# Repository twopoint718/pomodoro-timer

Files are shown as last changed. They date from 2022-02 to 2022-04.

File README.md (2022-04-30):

Pomodoro Timer
==============

A desktop pomodoro timer.

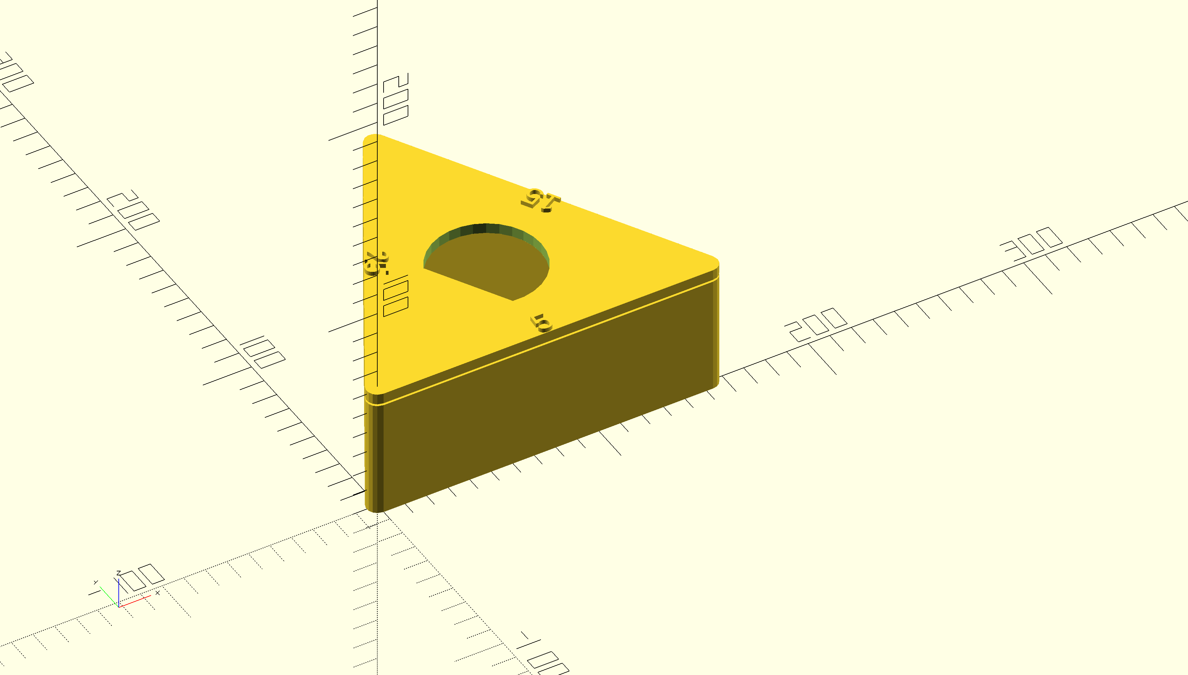
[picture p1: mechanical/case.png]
A rendered view of the case


Peripherals
-----------

- [PCD8544](https://learn.adafruit.com/nokia-5110-3310-monochrome-lcd) 84x48 pixel LCD screen (SPI-based)
- [LSM6DSL](https://www.st.com/resource/en/datasheet/lsm6dsl.pdf) (PDF) iNEMO inertial module always-on 3D accelerometer and 3D gyroscope (I2C)
- TIM (General-purpose timer, onboard)
- GPIO reset button
- UART (onboard)

Code
----

I've either referenced, ported, or otherwise used these open source projects in my own:

- [Adafruit GFX Library](https://github.com/Adafruit/Adafruit-GFX-Library), [BSD License](https://github.com/adafruit/Adafruit-GFX-Library/blob/master/license.txt)
- [STMicroelectronics LSM6DSL accelerometer/gyro driver](https://github.com/STMicroelectronics/stm32-lsm6dsl), [BSD License](https://opensource.org/licenses/BSD-3-Clause)
- [STMicroelectronics HAL code](https://www.st.com/resource/en/user_manual/um1884-description-of-stm32l4l4-hal-and-lowlayer-drivers-stmicroelectronics.pdf) (PDF)
- [8x8 VGA Font](https://github.com/dhepper/font8x8), Public Domain License

Building
--------

Be sure to have already installed the [Arm GNU Toolchain](https://developer.arm.com/tools-and-software/open-source-software/developer-tools/gnu-toolchain).
Then this project can be built by the Makefile in the root directory.

```
make -j
```

Building under Windows
----------------------

TODO

Presentations
-------------

- 8LU Keynote by Chris Wilson: Embedded–From the point of view of a web developer
  [YouTube Link](https://youtu.be/wSTIfWqJzPw)

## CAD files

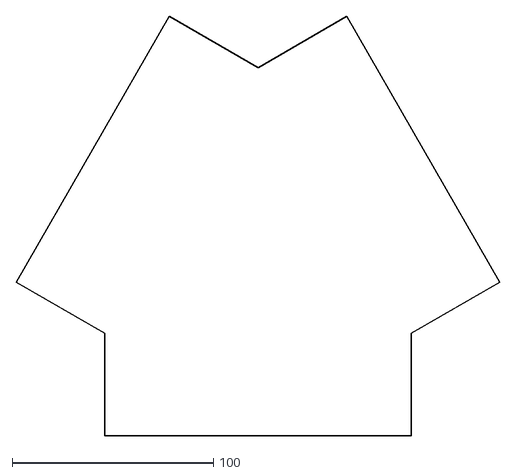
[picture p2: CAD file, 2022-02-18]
mechanical/pom_drawing.dxf
240.4 x 208.2

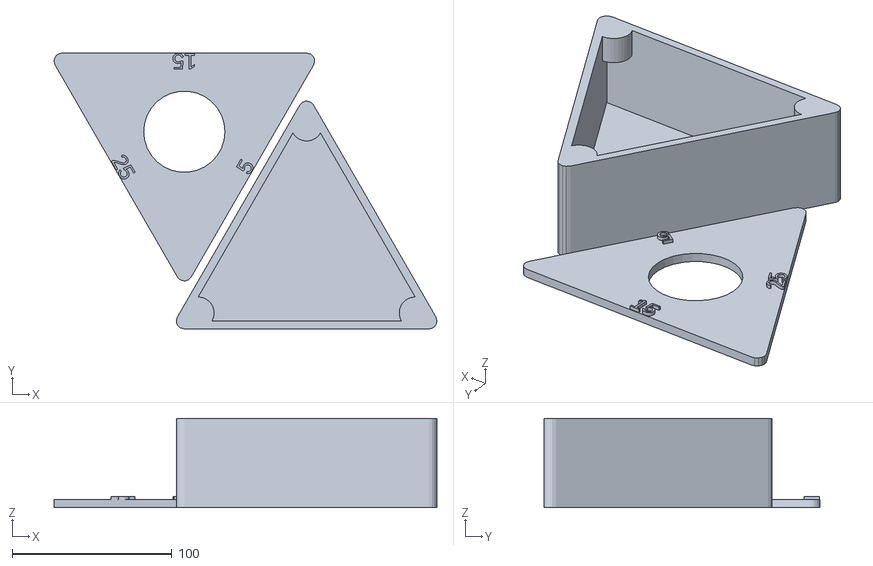
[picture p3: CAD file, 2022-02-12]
mechanical/case.stl
239.5 x 172.5 x 55.8

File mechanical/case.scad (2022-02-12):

/////////////////////////////////////////////////////////////////////
// Parameters

side_length = 153;  // 6"
wall_thickness = 5; // ~3/16"
side_height = 50.8 + wall_thickness; // 2" (from box bottom to lip)
lid_clearance = 30;
porthole_rad = 25.4;
magnet_r = 5;
magnet_tab_r = magnet_r + wall_thickness;
magnet_tab_h = 10;

/////////////////////////////////////////////////////////////////////
// Derived

lid_center = [
    0,
    lid_clearance + (side_length * sqrt(3))/3 // thx Pythagoras!
];

corners = [
    [0,0],
    [side_length * cos(60), side_length * sin(60)],
    [side_length, 0]
];

lid_corners = [
    [0, lid_clearance],
    [side_length * cos(60), side_length * sin(60) + lid_clearance],
    [-side_length/2, side_length * sin(60) + lid_clearance]
];

/////////////////////////////////////////////////////////////////////
// Modules

module MagnetTab(pos) {
    translate(pos) {
        difference() {
            linear_extrude(height = magnet_tab_h + wall_thickness) {
                offset(r = wall_thickness) {
                    circle(r = magnet_r);
                }
            }
            translate([0, 0, -1]) {
                linear_extrude(height = magnet_tab_h) {
                    circle(r = magnet_r);
                }
            }
        }
    }
}

/////////////////////////////////////////////////////////////////////
// Features

// Box Bottom
union() {
    // Wall
    linear_extrude(height = side_height) {
        difference() {
            offset(r = wall_thickness) {
                // outer wall
                polygon(corners);
            }
            // inner wall
            polygon(corners);
        }    
    }
    
    // Floor
    linear_extrude(height = wall_thickness) {
        offset(r = wall_thickness) {
            // outer wall
            polygon(corners);
        }
    }

    // Magnet Closure tab 1
    MagnetTab([
        (wall_thickness + magnet_r) * cos(30),
        (wall_thickness + magnet_r) * sin(30),
        side_height - wall_thickness - magnet_tab_h
    ]);

    // Magnet Closure tab 2
    MagnetTab([
        side_length/2,
        side_length * sin(60) - magnet_r - wall_thickness,
        side_height - wall_thickness - magnet_tab_h
    ]);
    
    // Magnet Closure tab 3
    MagnetTab([
        side_length - (wall_thickness + magnet_r) * cos(30),
        (wall_thickness + magnet_r) * sin(30),
        side_height - wall_thickness - magnet_tab_h
    ]);
}

// Box Lid
union() {
    difference() {
        linear_extrude(height = wall_thickness) {
            offset(r = wall_thickness) {
                polygon(lid_corners);
            }
        }
        translate([0, 0, -1]) {
            linear_extrude(height = wall_thickness + 2) {
                translate(lid_center) {
                    circle(r = porthole_rad);
                }
            }
        }
    }

    // Label (25)
    translate([-side_length/2 * cos(60), lid_clearance + side_length/2 * sin(60), 0]) {
        linear_extrude(height = wall_thickness + 2) {
            rotate(-60) {
                text("25", halign = "center", valign = "center");
            }
        }
    }

    // Label (5)
    translate([side_length/2 * cos(60), lid_clearance + side_length/2 * sin(60), 0]) {
        linear_extrude(height = wall_thickness + 2) {
            rotate(60) {
                text("5", halign = "center", valign = "center");
            }
        }
    }

    // Label (15)
    translate([0, lid_clearance + side_length * sin(60), 0]) {
        linear_extrude(height = wall_thickness + 2) {
            rotate(180) {
                text("15", halign = "center", valign = "center");
            }
        }
    }
}

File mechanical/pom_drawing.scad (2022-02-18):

l = 152.4;
h = 50.8;

// Triangle
polygon(points = [[0,0], [l * cos(60), l * sin(60)], [l, 0], [0, 0]]);

// Bottom side
polygon(points = [[0, -h], [l, -h], [l, 0], [0, 0]]);

// Right side
polygon(points = [
    [l, 0],
    [h*cos(30) + l, h*sin(30)],
    [l*cos(60) + h*cos(30), l*sin(60) + h*sin(30)],
    [l*cos(60), l*sin(60)]
]);

// Left side
polygon(points = [
    [l*cos(60), l*sin(60)],
    [l*cos(60) - h*cos(30), l*sin(60) + h*sin(30)],
    [h*cos(150), h*sin(150)],
    [0, 0]
]);

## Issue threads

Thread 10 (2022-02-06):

Implement PWM buzzer/tone

twopoint718, 2022-02-06:

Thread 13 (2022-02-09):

Refine 3D model

twopoint718, 2022-02-09:
Things to add or figure out:

- [ ] tabs for neodymium magnets (need to measure circumference)
- [ ] button holes/mounting
- [ ] drill holes/inserts for PCB mounting
- [ ] label orientation meanings (text in lid or symbol)
- [ ] general polish (fillet edges)

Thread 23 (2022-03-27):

Debugging Connectors?

twopoint718, 2022-03-27:
- [Tag-Connect](https://www.tag-connect.com/product/tc2050-idc-nl-10-pin-no-legs-cable-with-ribbon-connector)
- [SOICbite](https://github.com/SimonMerrett/SOICbite)
- [Mini SWD 0.05" Pitch Connector](https://www.adafruit.com/product/4048)

twopoint718, 2022-04-13:
Added both SOICbite and Tag-connect.

Closed 2022-04-13.

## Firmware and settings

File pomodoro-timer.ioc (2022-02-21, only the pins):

Mcu.UserName=STM32L475VGTx
PA0.Signal=UART4_TX
PA1.Signal=UART4_RX
PA2.GPIO_Label=LCD_RESET
PA2.Signal=GPIO_Output
PA3.GPIO_Label=LCD_DC
PA3.Signal=GPIO_Output
PA4.Signal=SPI1_NSS
PA5.Signal=SPI1_SCK
PA6.Signal=SPI1_MISO
PA7.Signal=SPI1_MOSI
PB10.Signal=I2C2_SCL
PB11.Signal=I2C2_SDA
PC13.Signal=GPXTI13

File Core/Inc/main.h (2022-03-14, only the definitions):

#define LCD_RESET_Pin GPIO_PIN_2
#define LCD_RESET_GPIO_Port GPIOA
#define LCD_DC_Pin GPIO_PIN_3
#define LCD_DC_GPIO_Port GPIOA
#define USER_BUTTON GPIO_PIN_13

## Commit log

2022-01-02 Configure SPI
2022-01-03 WIP: adding PCD8544 driver
2022-01-05 Add the LCD "Reset", "D/C (Data/Command)" pins
    [main.h, pomodoro-timer.ioc]
2022-01-05 WIP: display driver
2022-01-05 Configure LCD_CS pin
2022-01-10 Switch to "pair of .c/.h files" for gen'd peripherals
    - Adds
    - gpio.h/.c
    - spi.h/.c
2022-01-14 Drop LCD_CS GPIO and use hardware SPI NSS pin
2022-01-14 Fix bug in LCD_display() loop! Eek.
    [pcd8544.c]
2022-01-17 Set SPI data size to 8bit, slower speed
2022-01-20 Fix SPI timeout
2022-01-24 Add LSM6DSL driver from Mbed example project
2022-01-25 Integrate LSM6DSL Driver code
    - Enable UART
    - Add some Mbed OS/BSP code for IoT01 board
    - Add accel/gyro driver code
    - Move accelero/gyro under new `Components` directory
2022-01-25 WIP: enable I2C2
    - Looks like some of my custom code got bulldozed, plz check on it
    🐍 no step on snek!
2022-01-27 Enable UART4 (TX PA0, RX PA1)
2022-01-29 Remove UART
2022-01-29 Revert "Remove UART"
    ea29b3df27829001520359648c1781bb758fe39b
    [pomodoro-timer.ioc]
2022-01-31 USB is hard 🤯
2022-02-06 Remove USB support/middleware 🔌
2022-02-07 Successful UART test! ⌨️
2022-02-07 Update readme with STM HAL 💾
2022-02-08 Add case design
    [case.stl]
2022-02-09 Design case in OpenSCAD
    [case.scad, case.stl]
2022-02-10 Lower the number of facets for curves
    [case.scad]
2022-02-11 Add & modify Adafruit `draw_char` 🔤
2022-02-12 Case design improvements 📐
    [case.scad, case.stl]
2022-02-14 Fix dangling `{`, refactor includes
    [main.h, pcd8544.c]
2022-02-15 Add 8x8 font-drawing routines 🖋
2022-02-16 Enable TIM2 general-purpose timer ⏰
2022-02-17 Enable reloading the timer preload value ♻️
2022-02-17 Add `draw_clear_rect` function 🆑
2022-02-17 Start the TIM callback interrupt ⏱
2022-02-17 Set counter 80 million, interrupt period = 1sec
2022-02-17 Counter demo that uses timer interrupt! ⏲
2022-02-17 Flat case drawing, suitable for cutting ✂️
    [pom_drawing.scad]
2022-02-18 Read and display accelerometer data 🎢
2022-02-18 A "flat-pack" case design for laser cutting ⚡️🔦
    [pom_drawing.dxf, pom_drawing.scad]
2022-02-18 Redesign as connected polygons 🔺
    [pom_drawing.dxf, pom_drawing.scad]
2022-02-18 WIP: sketching out the state machine 🤖
2022-02-19 Enable I²C Event Interrupts
2022-02-20 WIP: fill out state machine, add orientation 🔝
2022-02-20 Finish `get_orientation` ↖️⬇️↗️
2022-02-20 Refactor states, debug state machine 🔧
2022-02-21 Set `USER` button as GPIO Input 🕹
2022-02-21 Configure `USER` button as an interrupt ⚠️
2022-02-21 And generate the actual EXT interrupt handler 😓
    - Need to check the box in the config tool to generate
    `EXTI15_10_IRQHandler` which in turn calls
    `HAL_GPIO_EXTI_IRQHandler(GPIO_PIN_13)`
2022-02-21 Handle `USER` button press (reset/cancel timer) 🚫
    [main.h]
2022-02-21 Display time, log orientation changes 🔁
2022-02-23 Add fritzing sketch
    [pomodoro-timer.fzz]
2022-02-25 Get rid of "Blinky" 💡
2022-02-25 Clean up (almost) all warnings, tweak diagram 🧬
2022-02-28 Stop tracking `.pomodoro-timer` GUI file
2022-03-03 Add case rendering 📸
2022-03-04 Add `num_poms` attr and increment attr (🍅++)
2022-03-07 Add release build directory 🚫
2022-03-09 WIP, build using makefile 📝
2022-03-10 Replace main with model/main 🪢
2022-03-11 Add headless build script 🎃
2022-03-11 WIP, Makefile surgery 👩🏼‍⚕️
2022-03-14 WIP: makefile 🗒
2022-03-14 WIP: Re-write Makefile to combine projects ♻️
2022-03-15 WIP: continue Makefile/build refactor 👻
2022-03-16 WIP: Even more Makefile tweaking 🔧
2022-03-16 WIP: Change to QV Cooperative Kernel. Add VSCode config 👯‍♀️
2022-03-19 Add build section to readme 👷‍♂️
2022-03-21 WIP: getting a clean build. Test. 🧼
2022-04-01 Add KiCad project
    [pomodorov2.kicad_pcb, pomodorov2.kicad_sch]
2022-04-03 Add some more parts to the v2 board 🔶
    [pomodorov2.kicad_pcb, pomodorov2.kicad_sch]
2022-04-04 Remove cortex header
    - remove main cortex header
    - tag-connect remains
    - soicbite remains
    [pomodorov2.kicad_pcb, pomodorov2.kicad_sch]
2022-04-05 Add components for chip, no routing 🚏
    [pomodorov2.kicad_pcb, pomodorov2.kicad_sch]
2022-04-07 Add Adafruit MDBT50Q-1MV2, remove nRF52832 QFN 🔄
    [pomodorov2.kicad_pcb, pomodorov2.kicad_sch]
2022-04-08 Adding test points, usb, crystals 💎
    [pomodorov2.kicad_pcb, pomodorov2.kicad_sch]
2022-04-09 Make schematic more legible 👓
    [pomodorov2.kicad_pcb, pomodorov2.kicad_sch]
2022-04-10 A little routing and schematic cleanup 🧹
    [pomodorov2.kicad_pcb, pomodorov2.kicad_sch]
2022-04-11 Some layout, schematic work 👷‍♂️
    [pomodorov2.kicad_pcb, pomodorov2.kicad_sch]
2022-04-12 Add Stemma connector, add signals 📶
    [pomodorov2.kicad_pcb, pomodorov2.kicad_sch]
2022-04-16 Add YouTube link 🎥
2022-04-18 Populate parts on board, remove stemma conn 🪓
    [pomodorov2.kicad_pcb, pomodorov2.kicad_sch]
2022-04-30 Change to YouTube direct link 🔗
2022-08-19 Migrate PCB project to pomodorov2 repo
    [pomodorov2.kicad_pcb]

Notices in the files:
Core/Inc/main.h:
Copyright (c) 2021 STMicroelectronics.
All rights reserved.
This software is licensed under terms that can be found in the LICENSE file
